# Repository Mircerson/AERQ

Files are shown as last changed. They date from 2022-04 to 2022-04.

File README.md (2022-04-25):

# AERQ - Indoor air quality monitor

## Introduction
This is the repository for AERQ, a USB-powered indoor air quality monitor using the
[here](/PCB/101-5/) Bosch BME688 sensor, running on mbed os.
It measures temperature, humidity, CO2 and IAQ using the BSEC 2.x library.
This data is then sent to The Things Network.
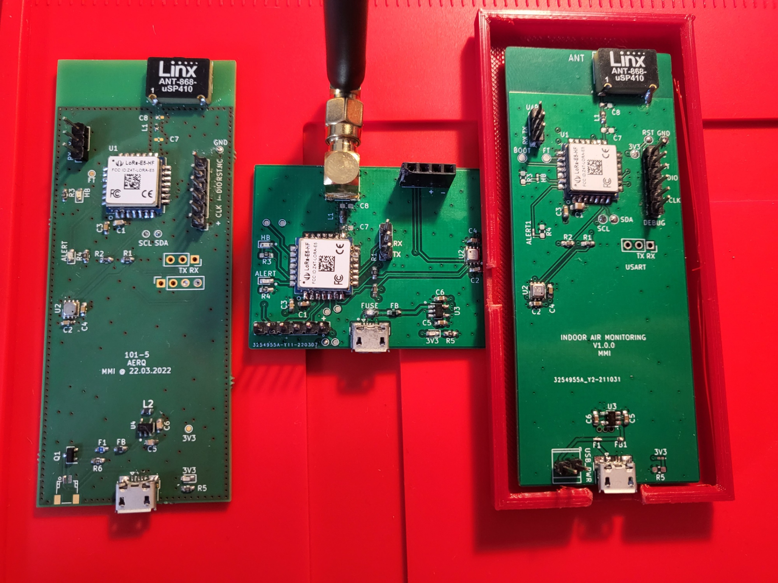
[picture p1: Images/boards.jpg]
Boards PCBs


## PCB
This project features a custom 4 layer board using the Seeed E5-LoRa and the Bosch BME688.
Two variants of the board, one with a chip antenna ( Linx USP-410 ) and one with a u.Fl connector.

Find more about the [STM32WL - Seeed E5-LoRa](https://www.seeedstudio.com/LoRa-E5-Wireless-Module-p-4745.html).

For the PCB with the integrated antenna, click here [here](/PCB/101-5/)

For the PCB with an external u.Fl connector, click [here](/PCB/101-3/)

## Code

The code runs on mbed os 6.15.1 with the latest LoRaWan stack.
Insert your TTN credentials in mbed_app.json before running the application.

This code features a custom target on mbed os which configures the RF switch properly and adds a few macros for the board.

See mbed_app.json and custom_targets.json for more details.

Thanks to [hallard](https://github.com/hallard/LoRa-E5-Breakout) for adding the support in the official mbed os custom target repository.

## Payload decoder for TTN
The payload should provide the following result:
TTN data TTN packet

```
function Decoder(bytes, port) {
  // Decode plain text; for testing only 
  //var statusFromDevice = String.fromCharCode.apply(null, bytes.slice(12,13))
  
  let StringOfBytes = String.fromCharCode.apply(null, bytes);
  
  var temperature;
  var humidity;
  var iaq;
  var iaqAccuracy;
  var CO2;
  
  const Array = StringOfBytes.split(" ");
  temperature = Array[0];
  humidity = Array[1];
  statusFromDevice = Array[2];
  iaq = Array[3];
  CO2 = Array[4];
  
  var statusToDisplay;
  
  if (statusFromDevice == "0"){
      statusToDisplay = "Device warming up";
  } else if(statusFromDevice == "1")
  {
      statusToDisplay = "Device is adjusting to the envinroment - calibrating";
  }else if(statusFromDevice == "2")
  {
      statusToDisplay = "Environment has changed - re-calibrating";
  }
  else if(statusFromDevice == "2")
  {
      statusToDisplay = "Environment has changed - re-calibrating";
  }
  else if(statusFromDevice == "3")
  {
      statusToDisplay = "Device is calibrated and running";
  }
  else if(statusFromDevice == "4")
  {
      statusToDisplay = "Error communicating with the IAQ sensor. Critical";
  }

  return {
      Humidity: humidity,
      //IAQAccuracy:String.fromCharCode.apply(null, bytes.slice(12,13)),
      IAQ:iaq,
      CO2:CO2,
      Temperature:temperature,
      Status:statusToDisplay
  };
}
```

## Android application

A simple KivyMD app was made for Android to receive packets:

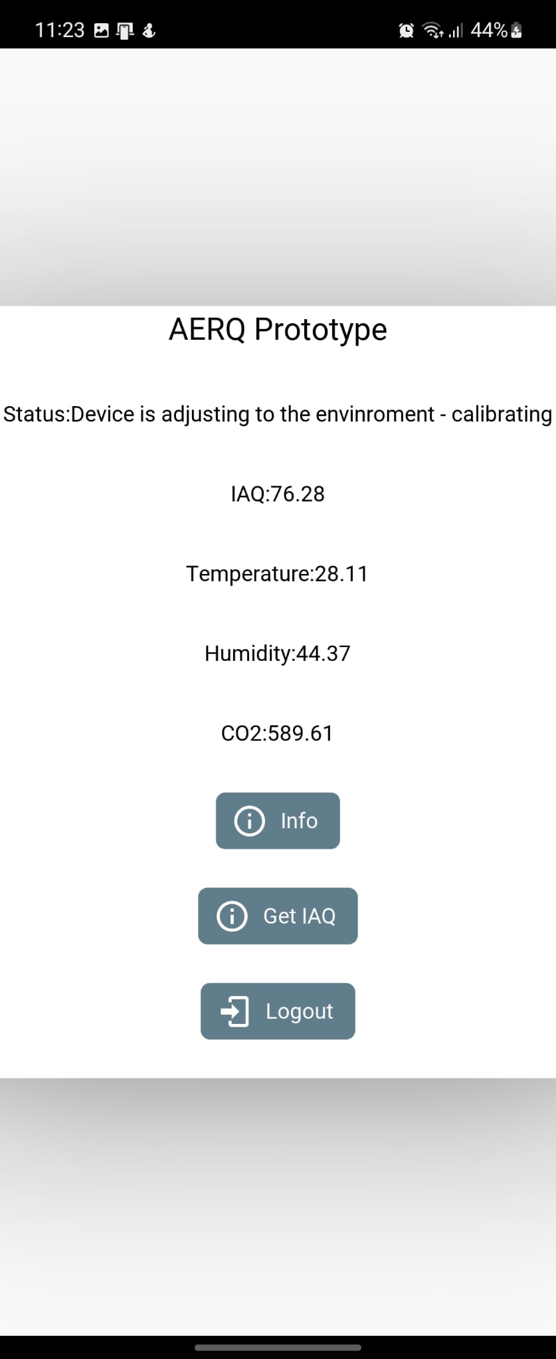
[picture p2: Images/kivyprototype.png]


## Azure IoT Central

Data can also be parsed through Azure IoT Hub to the Azure IoT Central

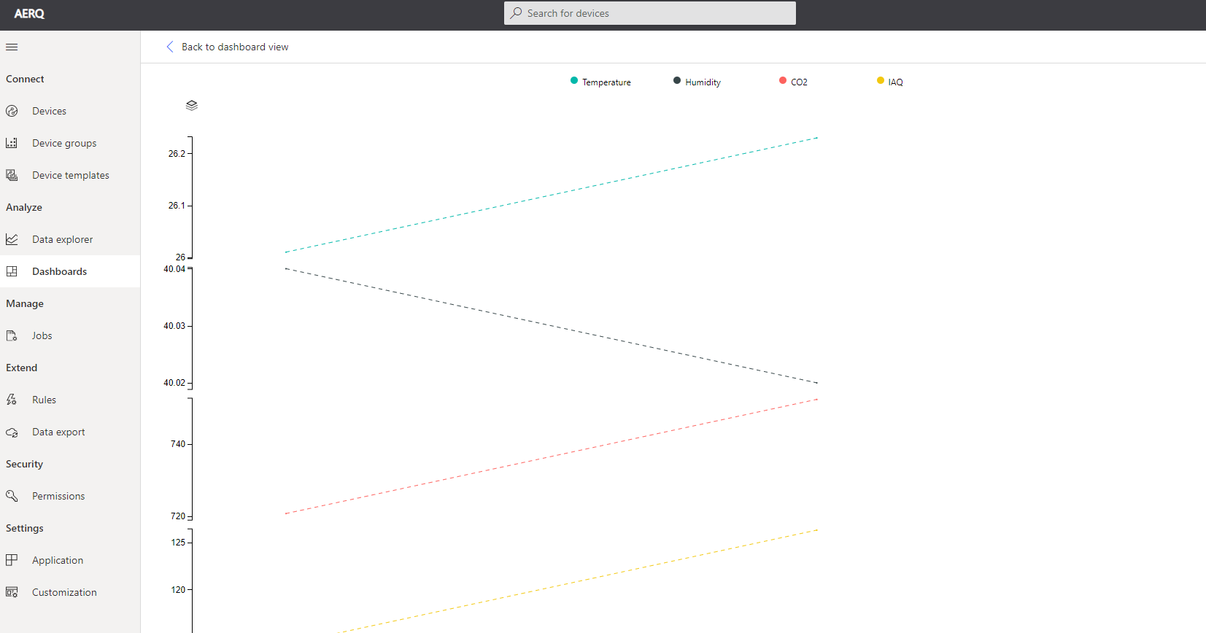
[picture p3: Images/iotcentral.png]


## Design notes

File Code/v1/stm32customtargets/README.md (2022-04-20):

# CUSTOM boards with STM32

Feel free to propose your custom boards support in mbed-os!

Table of Contents
=================

* [Usage](#usage)
* [GENERIC BOARDS](#generic-boards)
* [STM32F1](#stm32f1)
   * [BLUEPILL](#bluepill)
* [STM32F4](#stm32f4)
   * [CORE2](#core2)
* [STM32L0](#stm32l0)
   * [MURATA LPWAN Wireless Module](#murata-lpwan-wireless-module)
   * [MURATA Grasshopper](#murata-grasshopper)
   * [MURATA Gnat](#murata-gnat)
* [STM32L4](#stm32l4)
   * [STWIN SensorTile Wireless Industrial Node development kit](#stwin-sensortile-wireless-industrial-node-development-kit)
* [STM32WL](#stm32wl)
   * [Seeed Studio LoRa E5](#seeed-studio-lora-e5)
   * [Seeed Studio LoRa E5 Mini](#seeed-studio-lora-e5-mini)
   * [Seeed Studio LoRa E5 Dev Board](#seeed-studio-lora-e5-dev-board)
   * [Charles's LoRa-E5 breakout board](#charless-lora-e5-breakout-board)
   * [Charles's LoRa-E5 Tiny](#charless-lora-e5-tiny)
   * [RAK Wireless RAK3172](#rak-wireless-rak3172)
   * [Charles's RAK3172 breakout board](#charless-rak3172-breakout-board)
* [License](#license)
* [Contributions](#contributions)
   * [Automatic pull request checks](#automatic-pull-request-checks)
   * [Manual pull request checks](#manual-pull-request-checks)
   * [Automatic weekly non regression](#automatic-weekly-non-regression)

# Usage

In your application, clone this repo.

````
git clone https://github.com/ARMmbed/stm32customtargets.git
````

Copy custom_targets.json

````
cp stm32customtargets/custom_targets.json .
````

For some targets, you have to customize the configuration in your local mbed_app.json.

Details are explained for each target below, but you can also use the mbed_app_template.json file as example.

Then build your target with

- CLI1:
````
mbed compile -m XXX -t XXX
````

- CLI2:

Add in the application CMakeLists.txt:
````
add_subdirectory(stm32customtargets)
````
And build:
````
mbedtools compile -m XXX -t XXX
````

# GENERIC BOARDS

A "generic" board is a mbed-os "virtual" target with a pure STM32 MCU.

Goal is to make real custom boards creation very easy
as we ensure that build has alrady been tested.

Check the GENERIC_TARGET branch in this repo:

https://github.com/ARMmbed/stm32customtargets/tree/GENERIC_TARGET

# STM32F1

## BLUEPILL



MCU: STM32F103C8T6

TARGET: BLUEPILL_F103C8

source: https://os.mbed.com/users/hudakz/code/mbed-os-bluepill/

 (https://os.mbed.com/users/hudakz/code/STM32F103C8T6_Hello/)

# STM32F4

## CORE2 

MCU: STM32F407ZG

TARGET: CORE2

https://github.com/byq77/core2-mbed6-template



# STM32L0

## MURATA LPWAN Wireless Module

MCU: STM32L082CZ

TARGET: MTB_MURATA_ABZ

https://wireless.murata.com/type-abz-078.html

- LORA is not enabled by default. You need to update your local mbed_app.json file:

```json
{
    "target_overrides": {
        "MTB_MURATA_ABZ": {
            "target.components_add":             ["SX1276"],
            "sx1276-lora-driver.spi-mosi":       "LORA_SPI_MOSI",
            "sx1276-lora-driver.spi-miso":       "LORA_SPI_MISO",
            "sx1276-lora-driver.spi-sclk":       "LORA_SPI_SCLK",
            "sx1276-lora-driver.spi-cs":         "LORA_CS",
            "sx1276-lora-driver.reset":          "LORA_RESET",
            "sx1276-lora-driver.dio0":           "LORA_DIO0",
            "sx1276-lora-driver.dio1":           "LORA_DIO1",
            "sx1276-lora-driver.dio2":           "LORA_DIO2",
            "sx1276-lora-driver.dio3":           "LORA_DIO3",
            "sx1276-lora-driver.txctl":          "LORA_ANT_TX",
            "sx1276-lora-driver.rxctl":          "LORA_ANT_RX",
            "sx1276-lora-driver.pwr-amp-ctl":    "LORA_ANT_BOOST"
        }
    }
}
```

If you need to Low Power with VDD TXCO like [b-l072z-lrwan1](https://www.st.com/en/evaluation-tools/b-l072z-lrwan1.html), then you need JP9 positionned 1-2.
And reflect the pin used for that because it's defined to `NC` by default.

```json
{
    "target_overrides": {
        "MTB_MURATA_ABZ": {
            "sx1276-lora-driver.tcxo":           "PA_12"
        }
    }
}
```

## MURATA Grasshopper

MCU: STM32L082CZ



TARGET: GRASSHOPPER [TleraCorp](https://www.tindie.com/stores/tleracorp/)

- LORA is not enabled by default. You need to update your local mbed_app.json file:

```json
{
    "target_overrides": {
        "GRASSHOPPER": {
            "target.components_add":             ["SX1276"],
            "sx1276-lora-driver.spi-mosi":       "LORA_SPI_MOSI",
            "sx1276-lora-driver.spi-miso":       "LORA_SPI_MISO",
            "sx1276-lora-driver.spi-sclk":       "LORA_SPI_SCLK",
            "sx1276-lora-driver.spi-cs":         "LORA_CS",
            "sx1276-lora-driver.reset":          "LORA_RESET",
            "sx1276-lora-driver.dio0":           "LORA_DIO0",
            "sx1276-lora-driver.dio1":           "LORA_DIO1",
            "sx1276-lora-driver.dio2":           "LORA_DIO2",
            "sx1276-lora-driver.dio3":           "LORA_DIO3",
            "sx1276-lora-driver.txctl":          "LORA_ANT_TX",
            "sx1276-lora-driver.rxctl":          "LORA_ANT_RX",
            "sx1276-lora-driver.pwr-amp-ctl":    "LORA_ANT_BOOST",
            "sx1276-lora-driver.tcxo":           "LORA_VDD_TXCO"
        }
    }
}
```

## MURATA Gnat

MCU: STM32L082CZ



https://www.tindie.com/products/tleracorp/gnat-loragnss-asset-tracker/</img>

TARGET: GNAT [TleraCorp](https://www.tindie.com/products/tleracorp/gnat-loragnss-asset-tracker/)

- LORA is not enabled by default. You need to update your local mbed_app.json file:

```json
{
    "target_overrides": {
        "GNAT": {
            "target.components_add":             ["SX1276"],
            "sx1276-lora-driver.spi-mosi":       "LORA_SPI_MOSI",
            "sx1276-lora-driver.spi-miso":       "LORA_SPI_MISO",
            "sx1276-lora-driver.spi-sclk":       "LORA_SPI_SCLK",
            "sx1276-lora-driver.spi-cs":         "LORA_CS",
            "sx1276-lora-driver.reset":          "LORA_RESET",
            "sx1276-lora-driver.dio0":           "LORA_DIO0",
            "sx1276-lora-driver.dio1":           "LORA_DIO1",
            "sx1276-lora-driver.dio2":           "LORA_DIO2",
            "sx1276-lora-driver.dio3":           "LORA_DIO3",
            "sx1276-lora-driver.txctl":          "LORA_ANT_TX",
            "sx1276-lora-driver.rxctl":          "LORA_ANT_RX",
            "sx1276-lora-driver.pwr-amp-ctl":    "LORA_ANT_BOOST",
            "sx1276-lora-driver.tcxo":           "LORA_VDD_TXCO"
        }
    }
}
```

# STM32L4

## STWIN SensorTile Wireless Industrial Node development kit

MCU: STM32L4R9ZI



TARGET: STWIN

https://www.st.com/en/evaluation-tools/steval-stwinkt1.html

- BLE is enabled by default

# STM32WL

## Seeed Studio LoRa E5



MCU: STM32WLE5JC

TARGET: LORA_E5

https://www.seeedstudio.com/LoRa-E5-Wireless-Module-p-4745.html

LoRa-E5 use only RFO_HP for TX power, so for all boards using this module you need to add this to your `mbed_app.json` on section `target_overrides`

```json

   "LORA_E5": {
      "stm32wl-lora-driver.rf_switch_config": 2
   }
```

## Seeed Studio LoRa E5 Mini

TARGET: LORA_E5_MINI

Use LoRa E5 modulen basic board with USB/Serial and headers

https://www.seeedstudio.com/LoRa-E5-mini-STM32WLE5JC-p-4869.html

## Seeed Studio LoRa E5 Dev Board



TARGET: LORA_E5_DEV_BOARD

Use LoRa E5 module 

https://www.seeedstudio.com/LoRa-E5-Dev-Kit-p-4868.html

- RS485 Modbus
- all LoRa-E5 pins exposed
- temperature sensor
- buttons
- Led 
- GPIO to enable 3.3V and 5V for sensors
- some grove sonnectors (I2C, Serial, ..)
- Arduino form factor to plug shield

## Charles's LoRa-E5 breakout board

TARGET: LORA_E5_BREAKOUT



https://github.com/hallard/LoRa-E5-Breakout

Use LoRa E5 module and added

- FTDI 6 pins connector (:warning: **use 3.3V FTDI One, not 5V**)
- Exposed JTAG pins needed to flash module (PA13-SWDIO / PA14-SWCLK / RESET)
- Green Led on PB10 (LED1) reversed (1=OFF, 0=ON)
- Red Led on PB5 (LED2) reversed (1=OFF, 0=ON)

for debug LEDs of breakout so you need to add this to your `mbed_app.json` on section `target_overrides` and don't forget also the `rf_switch_config` seen above

```json
   "LORA_E5_BREAKOUT": {
      "stm32wl-lora-driver.rf_switch_config": 2,
      "stm32wl-lora-driver.debug_tx": "PB_5",
      "stm32wl-lora-driver.debug_rx": "PB_10",
      "stm32wl-lora-driver.debug_invert": 1
   }
```

## Charles's LoRa-E5 Tiny

TARGET: LORA_E5_TINY



https://github.com/hallard/LoRa-E5-Tiny

Use LoRa E5 module with CR2450 cell coin

- FTDI SMD 6 pads edge connector (:warning: **use 3.3V FTDI One, not 5V**)
- JTAG SMD 6 pads edge connector to flash module (PA13-SWDIO / PA14-SWCLK / PB3-SWO / RESET)
- Green Led on PB13
- Red Led on PA9
- 2 Tactile Switches (user PB4 and reset)
- Stemma QWIIC I2C connector
- PTH CR2450 battery holder

for debug LEDs of this board you need to add this to your `mbed_app.json` on section `target_overrides` and don't forget also the `rf_switch_config` seen above

```json
   "LORA_E5_TINY": {
      "stm32wl-lora-driver.rf_switch_config": 2,
      "stm32wl-lora-driver.debug_tx": "PB_13",
      "stm32wl-lora-driver.debug_rx": "PA_9"
   }
```

## RAK Wireless RAK3172



MCU: STM32WLE5CC

TARGET: RAK3172

RAK3172 use only RFO_HP for TX power and no TXCO so for all boards using this module you need to add this to your `mbed_app.json` on section `target_overrides`

```json

   "RAK3172": {
      "stm32wl-lora-driver.rf_switch_config": 2,
      "stm32wl-lora-driver.crystal_select" : 0
   }
```

## Charles's RAK3172 breakout board

TARGET: RAK3172_BREAKOUT



https://github.com/hallard/RAK3172-Breakout

Use RAK3172 and added

- FTDI 6 pins connector (:warning: **use 3.3V FTDI One, not 5V**)
- Exposed JTAG pins needed to flash module (PA13-SWDIO / PA14-SWCLK / RESET)
- Green Led on PA10 (LED1) reversed (1=OFF, 0=ON)
- Red Led on PA9 (LED2) reversed (1=OFF, 0=ON)
- SMD CR2450 battery holder

For debug LEDs of breakout so you need to add this to your `mbed_app.json` on section `target_overrides` and don't forget also the `rf_switch_config` and `crystal_select` seen above

```json
   "RAK3172_BREAKOUT": {
      "stm32wl-lora-driver.rf_switch_config": 2,
      "stm32wl-lora-driver.crystal_select" : 0,
      "stm32wl-lora-driver.debug_tx": "PA_10",
      "stm32wl-lora-driver.debug_rx": "PA_9",
      "stm32wl-lora-driver.debug_invert": 1
   }
```

# License

The software is provided under the [Apache-2.0 license](LICENSE-apache-2.0.txt).

# Contributions

Contributions to this project are accepted under the same license.

## Automatic pull request checks

- Build with CLI1 should be OK
```
python aci_build.py
```

- Build with CLI2 should be OK
```
python aci_build.py --cli2
```

Note that build is using the mbed_app_template.json file as configuration file.

- Standard Pin Names check should be OK

https://os.mbed.com/docs/mbed-os/latest/apis/standard-pin-names.html

```
python aci_build.py --pin
```

## Manual pull request checks

- Each target in custom_targets.json should be described in the README.md file

```
## <Full target name>

MCU: <STM32 MCU>

TARGET: <Target name for build>

<Link to a webpage describing this board>

<all other info is optional>

```

Note we limit image size to 200

- Keep Table of Contents up to date

## Automatic weekly non regression

A full non regression is executed each week-end

```
python aci_build.py --all
python aci_build.py --all --baremetal
python aci_build.py --all --cli2
python aci_build.py --all --cli2 --baremetal
python aci_build.py --all --pin
```

See in https://github.com/ARMmbed/stm32customtargets/actions

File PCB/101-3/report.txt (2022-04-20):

Info: Processing component "R2:/617AAB6E:Resistor_SMD:R_0603_1608Metric_Pad0.98x0.95mm_HandSolder".
Info: Processing component "GND1:/61981146:TestPoint:TestPoint_Pad_D1.5mm".
Info: Processing component "HB1:/61853D6C:LED_SMD:LED_0201_0603Metric_Pad0.64x0.40mm_HandSolder".
Info: Processing component "J1:/617BE23C:Connector_PinHeader_2.54mm:PinHeader_1x06_P2.54mm_Vertical".
Info: Processing component "J2:/61963625:TerminalBlock_TE-Connectivity:TerminalBlock_TE_282834-2_1x02_P2.54mm_Horizontal".
Info: Processing component "J3:/6180F261:Connector_USB:USB_Micro-B_Amphenol_10103594-0001LF_Horizontal".
Info: Processing component "3V3:/618832CE:LED_SMD:LED_0201_0603Metric_Pad0.64x0.40mm_HandSolder".
Info: Processing component "J5:/6195374E:Connector_PinSocket_2.54mm:PinSocket_1x03_P2.54mm_Vertical".
Info: Processing component "J6:/621E8932:Connector_PinHeader_2.54mm:PinHeader_1x01_P2.54mm_Vertical".
Info: Processing component "L1:/619CD27C:Capacitor_SMD:C_0603_1608Metric_Pad1.08x0.95mm_HandSolder".
Info: Processing component "R1:/617A9750:Resistor_SMD:R_0603_1608Metric_Pad0.98x0.95mm_HandSolder".
Info: Processing component "J4:/618D8888:Connector_PinSocket_2.54mm:PinSocket_1x03_P2.54mm_Vertical".
Info: Processing component "R3:/61856ED3:Resistor_SMD:R_0603_1608Metric_Pad0.98x0.95mm_HandSolder".
Info: Processing component "R4:/618772FD:Resistor_SMD:R_0603_1608Metric_Pad0.98x0.95mm_HandSolder".
Info: Processing component "R5:/618832D5:Resistor_SMD:R_0603_1608Metric_Pad0.98x0.95mm_HandSolder".
Info: Processing component "RST1:/6197BBD1:TestPoint:TestPoint_Pad_D1.5mm".
Info: Processing component "SCL1:/61906980:TestPoint:TestPoint_Pad_D1.5mm".
Info: Processing component "SDA1:/619098E4:TestPoint:TestPoint_Pad_D1.5mm".
Info: Processing component "U1:/6164AFD9:mmilibrary:LoRa-E5".
Info: Processing component "U2:/61802F1D:Package_LGA:Bosch_LGA-8_3x3mm_P0.8mm_ClockwisePinNumbering".
Info: Processing component "U3:/61787A56:Package_TO_SOT_SMD:SOT-23-5_HandSoldering".
Info: Processing component "C3:/61781AAA:Capacitor_SMD:C_0603_1608Metric_Pad1.08x0.95mm_HandSolder".
Info: Processing component "3V3_OUT1:/618F8508:TestPoint:TestPoint_Pad_D1.5mm".
Info: Processing component "ALERT1:/618772F6:LED_SMD:LED_0201_0603Metric_Pad0.64x0.40mm_HandSolder".
Info: Processing component "BOOT_TP1:/6197CBDD:TestPoint:TestPoint_Pad_D1.5mm".
Info: Processing component "C1:/61772FC0:Capacitor_SMD:C_0603_1608Metric_Pad1.08x0.95mm_HandSolder".
Info: Processing component "C2:/6179A095:Capacitor_SMD:C_0603_1608Metric_Pad1.08x0.95mm_HandSolder".
Info: Processing component "C4:/6179A0A9:Capacitor_SMD:C_0603_1608Metric_Pad1.08x0.95mm_HandSolder".
Info: Processing component "C5:/618C5A71:Capacitor_SMD:C_0603_1608Metric_Pad1.08x0.95mm_HandSolder".
Info: Processing component "C6:/618C69FF:Capacitor_SMD:C_0603_1608Metric_Pad1.08x0.95mm_HandSolder".
Info: Processing component "C7:/619CC8DD:Capacitor_SMD:C_0603_1608Metric_Pad1.08x0.95mm_HandSolder".
Info: Processing component "C8:/619CDAB6:Capacitor_SMD:C_0603_1608Metric_Pad1.08x0.95mm_HandSolder".
Info: Processing component "E1:/619C1B4A:mmilibrary:XDCR_ANT-868-USP410".
Info: Processing component "FB1:/618FFA2B:Capacitor_SMD:C_0201_0603Metric_Pad0.64x0.40mm_HandSolder".
Info: Processing component "FT1:/619C09A1:TestPoint:TestPoint_Pad_D1.5mm".
Info: Processing component "F1:/61906770:Capacitor_SMD:C_0201_0603Metric_Pad0.64x0.40mm_HandSolder".
Add net Net-(U1-Pad20).
Add net ADC_IN3.
Connect U1 pin 7 to ADC_IN3.
Add net Net-(U1-Pad11).
Connect U1 pin 11 to Net-(U1-Pad11).
Add net Net-(U1-Pad8).
Connect U1 pin 8 to Net-(U1-Pad8).
Add net Net-(U1-Pad12).
Connect U1 pin 12 to Net-(U1-Pad12).
Add net Net-(U1-Pad13).
Connect U1 pin 13 to Net-(U1-Pad13).
Change GND reference to GND1.
Connect U1 pin 20 to Net-(U1-Pad20).
Add net Net-(U1-Pad21).
Connect U1 pin 21 to Net-(U1-Pad21).
Add net Net-(U1-Pad25).
Connect U1 pin 25 to Net-(U1-Pad25).
Add net Net-(U1-Pad26).
Connect U1 pin 26 to Net-(U1-Pad26).
Change 3V3 reference to 3V3_OUT1.
Connect USB_PWR pin 4 to Net-(J3-Pad4).
Add net Net-(J1-Pad6).
Add net Net-(J3-Pad2).
Connect USB_PWR pin 2 to Net-(J3-Pad2).
Change ANT reference to E1.
Change UART reference to J4.
Change USB_PWR reference to J3.
Change USART reference to J5.
Add net Net-(E1-Pad2).
Add J6 (footprint "Connector_PinHeader_2.54mm:PinHeader_1x01_P2.54mm_Vertical").
Connect ANT pin 2 to Net-(E1-Pad2).
Connect DEBUG pin 6 to Net-(J1-Pad6).
Connect USB_PWR pin 3 to Net-(J3-Pad3).
Change DEBUG reference to J1.
Change FT reference to FT1.
Add net Net-(J3-Pad3).
Change HB reference to HB1.
Change RST reference to RST1.
Change BOOT reference to BOOT_TP1.
Change SCL reference to SCL1.
Add net Net-(J3-Pad4).
Change SDA reference to SDA1.

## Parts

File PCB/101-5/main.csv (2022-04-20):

Source: | C:\Github\Indoor-Air-Quality-BME688-STM32WLE5JC\KiCad\Indoor Air Monitor\101-4\main.sch
Date: | 13/03/2022 15:14
Tool: | Eeschema (5.1.10)-1
Generator: | C:\Program Files\KiCad\bin\scripting\plugins/bom_csv_grouped_by_value.py
Component Count: | 35
Individual Components:
Item | Qty | Reference(s) | Value | LibPart | Footprint | Datasheet | MANUFACTURER | MAXIMUM_PACKAGE_HEIGHT | PARTREV | STANDARD
 |  | 3V1 | PWR | Device:LED_Small | LED_SMD:LED_0603_1608Metric_Pad1.05x0.95mm_HandSolder | ~
 |  | 3V3_OUT1 | 3V3_TP | Connector:TestPoint_Small | TestPoint:TestPoint_Pad_D1.0mm | ~
 |  | ALERT1 | ALERT | Device:LED_Small | LED_SMD:LED_0603_1608Metric_Pad1.05x0.95mm_HandSolder | ~
 |  | C1 | 100nF | Device:C_Small | Capacitor_SMD:C_0603_1608Metric_Pad1.08x0.95mm_HandSolder | ~
 |  | C2 | 100nF | Device:C_Small | Capacitor_SMD:C_0603_1608Metric_Pad1.08x0.95mm_HandSolder | ~
 |  | C3 | 4.7uF | Device:C_Small | Capacitor_SMD:C_0603_1608Metric_Pad1.08x0.95mm_HandSolder | ~
 |  | C4 | 100nF | Device:C_Small | Capacitor_SMD:C_0603_1608Metric_Pad1.08x0.95mm_HandSolder | ~
 |  | C5 | 1uF | Device:C_Small | Capacitor_SMD:C_0603_1608Metric_Pad1.08x0.95mm_HandSolder | ~
 |  | C6 | 1uF | Device:C_Small | Capacitor_SMD:C_0603_1608Metric_Pad1.08x0.95mm_HandSolder | ~
 |  | C7 | DNP | Device:C_Small | Capacitor_SMD:C_0603_1608Metric_Pad1.08x0.95mm_HandSolder | ~
 |  | C8 | DNP | Device:C_Small | Capacitor_SMD:C_0603_1608Metric_Pad1.08x0.95mm_HandSolder | ~
 |  | CON_DEBUG1 | Conn_01x02_Male | Connector:Conn_01x02_Male | Connector_PinHeader_2.54mm:PinHeader_1x02_P2.54mm_Vertical | ~
 |  | E1 | ANT-868-USP410 | main-rescue:ANT-868-USP410-Antenna | mmilibrary:XDCR_ANT-868-USP410 |  | Linx | 2.9 mm | DS20241-03ANT | Manufacturer Recommendations
 |  | F1 | 300mA Fuse | Device:Polyfuse_Small | Resistor_SMD:R_0603_1608Metric_Pad0.98x0.95mm_HandSolder | ~
 |  | FB1 | FB | Device:Ferrite_Bead_Small | Resistor_SMD:R_0603_1608Metric_Pad0.98x0.95mm_HandSolder | ~
 |  | FT1 | FT_TP | Connector:TestPoint_Small | TestPoint:TestPoint_Pad_D1.0mm | ~
 |  | GND1 | GND | Connector:TestPoint_Small | TestPoint:TestPoint_Pad_D1.0mm | ~
 |  | HB1 | HEARTBEAT | Device:LED_Small | LED_SMD:LED_0603_1608Metric_Pad1.05x0.95mm_HandSolder | ~
 |  | J1 | 1x6 header | Connector:Conn_01x06_Male | Connector_PinHeader_2.54mm:PinHeader_1x06_P2.54mm_Vertical | ~
 |  | J2 | Screw_Terminal_01x02 | Connector:Screw_Terminal_01x02 | TerminalBlock_TE-Connectivity:TerminalBlock_TE_282834-2_1x02_P2.54mm_Horizontal | ~
 |  | J4 | Conn_01x03 | Connector_Generic:Conn_01x03 | Connector_PinSocket_2.54mm:PinSocket_1x03_P2.54mm_Vertical | ~
 |  | J5 | Conn_01x03 | Connector_Generic:Conn_01x03 | Connector_PinSocket_2.54mm:PinSocket_1x03_P2.54mm_Vertical | ~
 |  | J6 | Conn_01x04_Female | Connector:Conn_01x04_Female | Connector_PinSocket_2.54mm:PinSocket_1x04_P2.54mm_Vertical | ~
 |  | L1 | DNP | Device:L_Small | Capacitor_SMD:C_0603_1608Metric_Pad1.08x0.95mm_HandSolder | ~
 |  | R1 | 4.7k | Device:R_Small | Resistor_SMD:R_0603_1608Metric_Pad0.98x0.95mm_HandSolder | ~
 |  | R2 | 4.7k | Device:R_Small | Resistor_SMD:R_0603_1608Metric_Pad0.98x0.95mm_HandSolder | ~
 |  | R3 | 1.8k | Device:R_Small | Resistor_SMD:R_0603_1608Metric_Pad0.98x0.95mm_HandSolder | ~
 |  | R4 | 1.8k | Device:R_Small | Resistor_SMD:R_0603_1608Metric_Pad0.98x0.95mm_HandSolder | ~
 |  | R5 | 1.8k | Device:R_Small | Resistor_SMD:R_0603_1608Metric_Pad0.98x0.95mm_HandSolder | ~
 |  | SCL1 | SCL_TP | Connector:TestPoint_Small | TestPoint:TestPoint_Pad_D1.0mm | ~
 |  | SDA1 | SDA_TP | Connector:TestPoint_Small | TestPoint:TestPoint_Pad_D1.0mm | ~
 |  | U1 | LoRa-E5 | LoRa-E5:LoRa-E5 | mmilibrary:LoRa-E5
 |  | U2 | BME688 | main-rescue:BME688-BME688 | Package_LGA:Bosch_LGA-8_3x3mm_P0.8mm_ClockwisePinNumbering
 |  | U3 | TLV70333DBVR | mmiSymbol:TLV70333DBVR | Package_TO_SOT_SMD:SOT-23-5_HandSoldering | https://www.ti.com/lit/ds/symlink/tlv703.pdf?ts=1635229150191
 |  | USB_PWR1 | USB_B_Micro | Connector:USB_B_Micro | Connector_USB:USB_Micro-B_Amphenol_10103594-0001LF_Horizontal | ~
Collated Components:
Item | Qty | Reference(s) | Value | LibPart | Footprint | Datasheet | MANUFACTURER | MAXIMUM_PACKAGE_HEIGHT | PARTREV | STANDARD
1 | 1 | 3V1 | PWR | Device:LED_Small | LED_SMD:LED_0603_1608Metric_Pad1.05x0.95mm_HandSolder | ~
2 | 1 | 3V3_OUT1 | 3V3_TP | Connector:TestPoint_Small | TestPoint:TestPoint_Pad_D1.0mm | ~
3 | 1 | ALERT1 | ALERT | Device:LED_Small | LED_SMD:LED_0603_1608Metric_Pad1.05x0.95mm_HandSolder | ~
4 | 3 | C1, C2, C4 | 100nF | Device:C_Small | Capacitor_SMD:C_0603_1608Metric_Pad1.08x0.95mm_HandSolder | ~
5 | 1 | C3 | 4.7uF | Device:C_Small | Capacitor_SMD:C_0603_1608Metric_Pad1.08x0.95mm_HandSolder | ~
6 | 2 | C5, C6 | 1uF | Device:C_Small | Capacitor_SMD:C_0603_1608Metric_Pad1.08x0.95mm_HandSolder | ~
7 | 2 | C7, C8 | DNP | Device:C_Small | Capacitor_SMD:C_0603_1608Metric_Pad1.08x0.95mm_HandSolder | ~
8 | 1 | CON_DEBUG1 | Conn_01x02_Male | Connector:Conn_01x02_Male | Connector_PinHeader_2.54mm:PinHeader_1x02_P2.54mm_Vertical | ~
9 | 1 | E1 | ANT-868-USP410 | main-rescue:ANT-868-USP410-Antenna | mmilibrary:XDCR_ANT-868-USP410 |  | Linx | 2.9 mm | DS20241-03ANT | Manufacturer Recommendations
10 | 1 | F1 | 300mA Fuse | Device:Polyfuse_Small | Resistor_SMD:R_0603_1608Metric_Pad0.98x0.95mm_HandSolder | ~
11 | 1 | FB1 | FB | Device:Ferrite_Bead_Small | Resistor_SMD:R_0603_1608Metric_Pad0.98x0.95mm_HandSolder | ~
12 | 1 | FT1 | FT_TP | Connector:TestPoint_Small | TestPoint:TestPoint_Pad_D1.0mm | ~
13 | 1 | GND1 | GND | Connector:TestPoint_Small | TestPoint:TestPoint_Pad_D1.0mm | ~
14 | 1 | HB1 | HEARTBEAT | Device:LED_Small | LED_SMD:LED_0603_1608Metric_Pad1.05x0.95mm_HandSolder | ~
15 | 1 | J1 | 1x6 header | Connector:Conn_01x06_Male | Connector_PinHeader_2.54mm:PinHeader_1x06_P2.54mm_Vertical | ~
16 | 1 | J2 | Screw_Terminal_01x02 | Connector:Screw_Terminal_01x02 | TerminalBlock_TE-Connectivity:TerminalBlock_TE_282834-2_1x02_P2.54mm_Horizontal | ~
17 | 2 | J4, J5 | Conn_01x03 | Connector_Generic:Conn_01x03 | Connector_PinSocket_2.54mm:PinSocket_1x03_P2.54mm_Vertical | ~
18 | 1 | J6 | Conn_01x04_Female | Connector:Conn_01x04_Female | Connector_PinSocket_2.54mm:PinSocket_1x04_P2.54mm_Vertical | ~
19 | 1 | L1 | DNP | Device:L_Small | Capacitor_SMD:C_0603_1608Metric_Pad1.08x0.95mm_HandSolder | ~
20 | 2 | R1, R2 | 4.7k | Device:R_Small | Resistor_SMD:R_0603_1608Metric_Pad0.98x0.95mm_HandSolder | ~
21 | 3 | R3, R4, R5 | 1.8k | Device:R_Small | Resistor_SMD:R_0603_1608Metric_Pad0.98x0.95mm_HandSolder | ~
22 | 1 | SCL1 | SCL_TP | Connector:TestPoint_Small | TestPoint:TestPoint_Pad_D1.0mm | ~
23 | 1 | SDA1 | SDA_TP | Connector:TestPoint_Small | TestPoint:TestPoint_Pad_D1.0mm | ~
24 | 1 | U1 | LoRa-E5 | LoRa-E5:LoRa-E5 | mmilibrary:LoRa-E5
25 | 1 | U2 | BME688 | main-rescue:BME688-BME688 | Package_LGA:Bosch_LGA-8_3x3mm_P0.8mm_ClockwisePinNumbering
26 | 1 | U3 | TLV70333DBVR | mmiSymbol:TLV70333DBVR | Package_TO_SOT_SMD:SOT-23-5_HandSoldering | https://www.ti.com/lit/ds/symlink/tlv703.pdf?ts=1635229150191
27 | 1 | USB_PWR1 | USB_B_Micro | Connector:USB_B_Micro | Connector_USB:USB_Micro-B_Amphenol_10103594-0001LF_Horizontal | ~

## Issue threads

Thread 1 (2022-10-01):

Antenna performance?

marcpiulachs, 2022-10-01:
Hi, I'm looking to build a similar device with a Lora E5 with sensor and since I'm not an expert on the RF field and looking for similar designs to learn from I came across your AERQ project, I would prefer to use a built in antena on the pcb rather than an external one but I'm a little worried about the performance, have you tested the range with your device?

Mircerson, 2022-10-02:
Range is pretty good. Maximum I got was around 1 km with the Linx antenna( with LoS but in an urban environment ). Expect to get a whole building covered.

Keep in mind if you end up doing a low-power design that the E5-LoRa is hard wired to use the High TX power path, so it does use quite a bit of power to do the transmission.

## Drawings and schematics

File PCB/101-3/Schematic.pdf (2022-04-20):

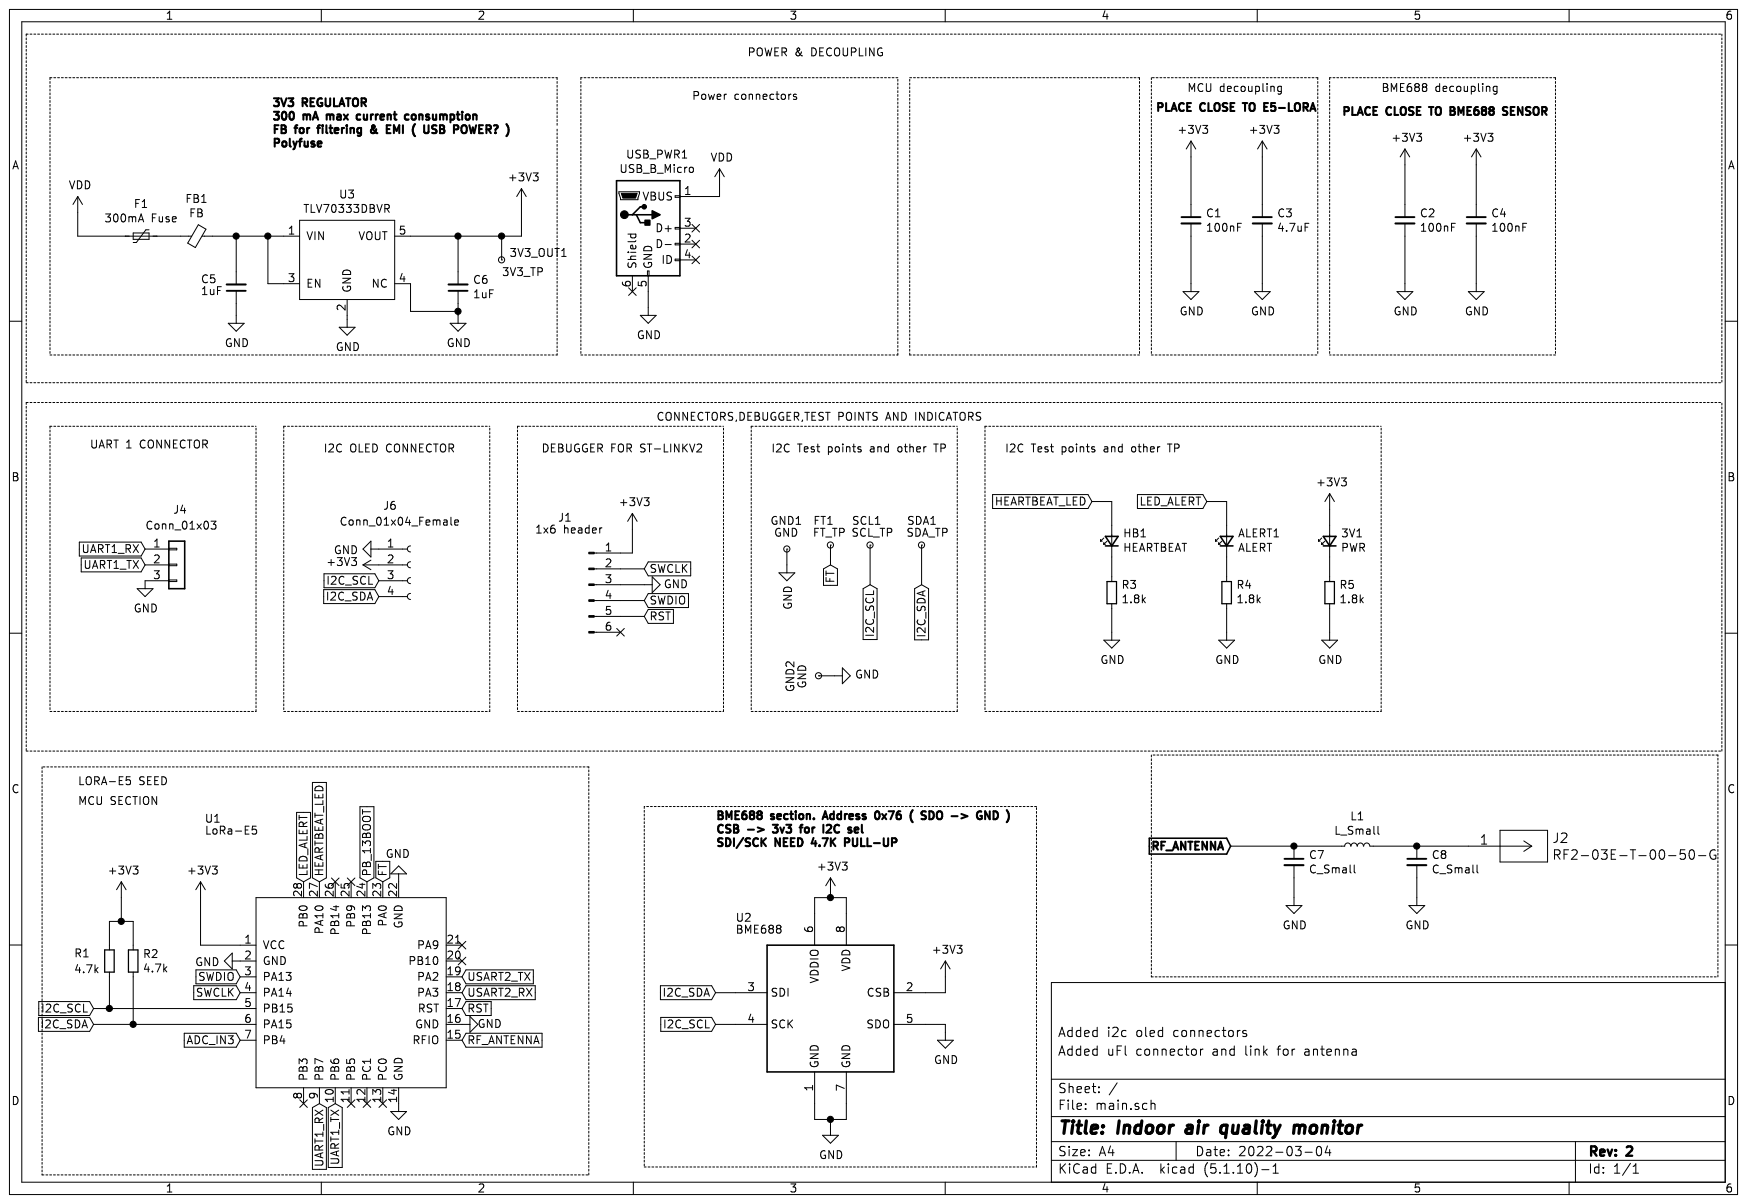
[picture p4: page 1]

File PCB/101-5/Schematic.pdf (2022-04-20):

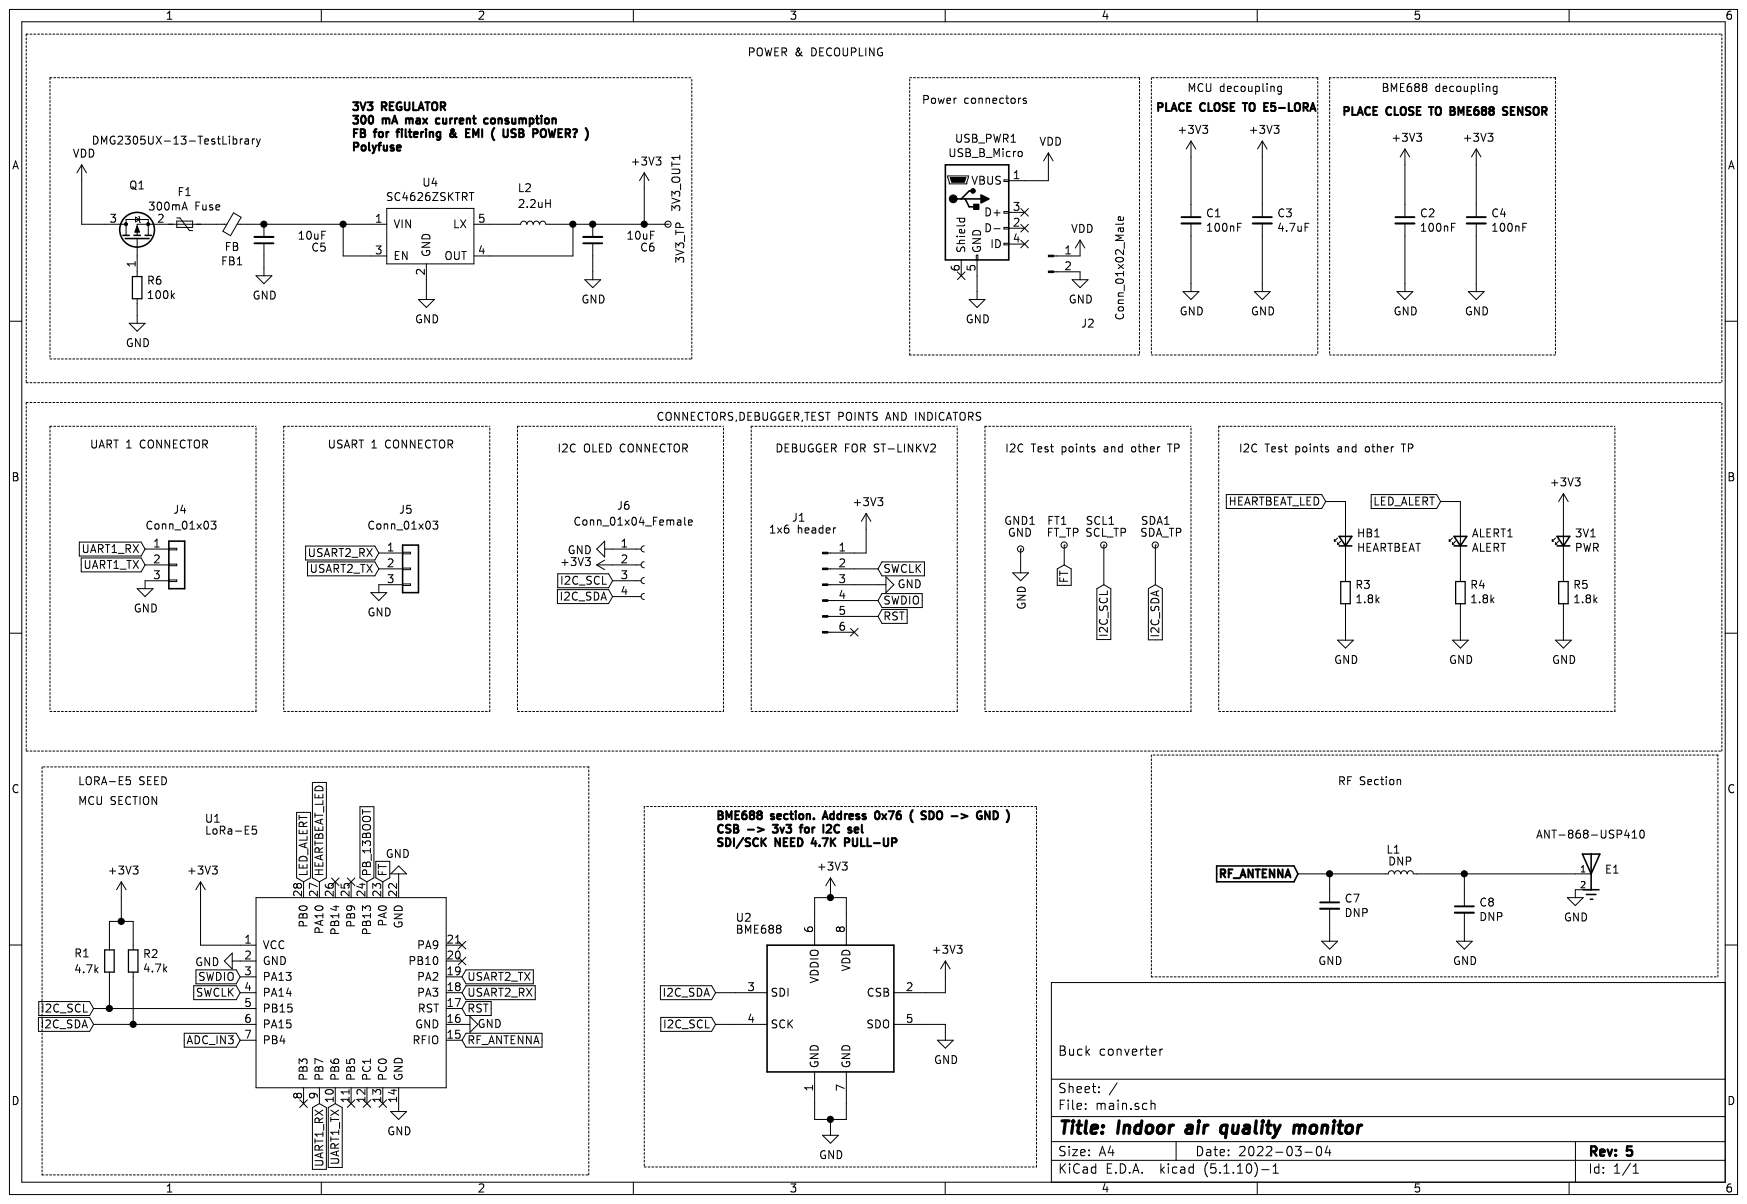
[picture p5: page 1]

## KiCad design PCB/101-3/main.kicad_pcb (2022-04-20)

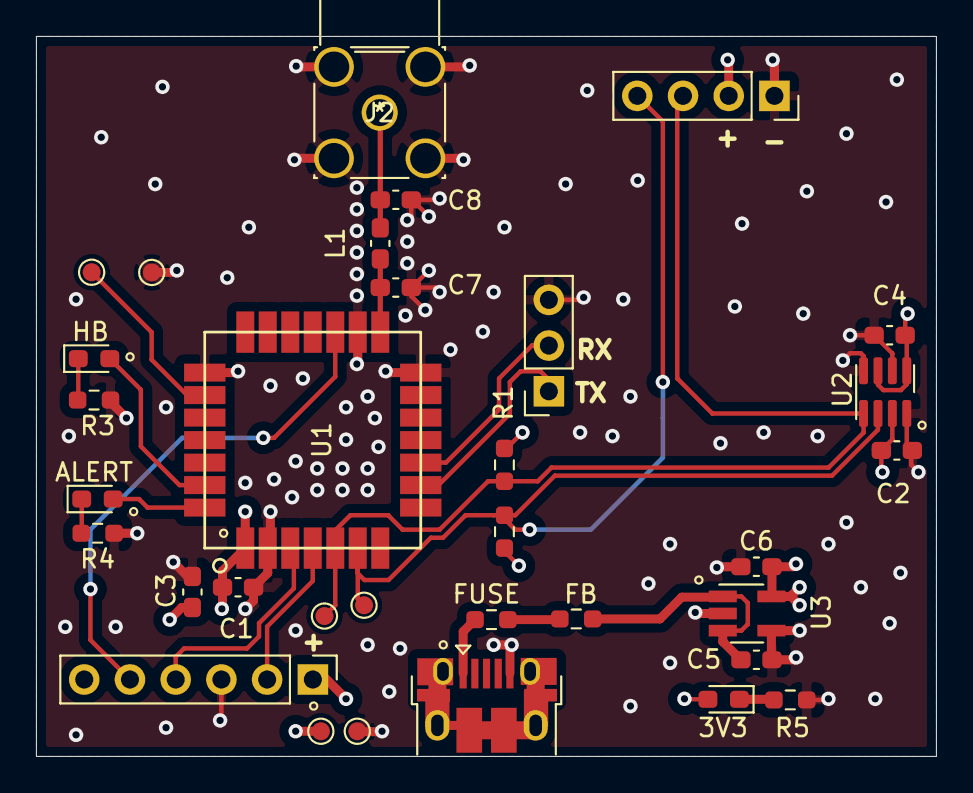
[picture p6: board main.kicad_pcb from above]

Board: 4 copper layers, 50.0 x 40.0 mm, 33 parts (0 on the bottom side), 20 nets.

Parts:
3V1: PWR; LED_0603_1608Metric_Pad1.05x0.95mm_HandSolder
3V3_OUT1: 3V3_TP; TestPoint_Pad_D1.0mm
ALERT1: ALERT; LED_0603_1608Metric_Pad1.05x0.95mm_HandSolder
C1, C2, C4: 100nF; C_0603_1608Metric_Pad1.08x0.95mm_HandSolder
C3: 4.7uF; C_0603_1608Metric_Pad1.08x0.95mm_HandSolder
C5, C6: 1uF; C_0603_1608Metric_Pad1.08x0.95mm_HandSolder
C7, C8: C_Small; C_0603_1608Metric_Pad1.08x0.95mm_HandSolder
F1: 300mA Fuse; R_0603_1608Metric_Pad0.98x0.95mm_HandSolder
FB1: FB; R_0603_1608Metric_Pad0.98x0.95mm_HandSolder
FT1: FT_TP; TestPoint_Pad_D1.0mm
GND1, GND2: GND; TestPoint_Pad_D1.0mm
HB1: HEARTBEAT; LED_0603_1608Metric_Pad1.05x0.95mm_HandSolder
J1: 1x6 header; PinHeader_1x06_P2.54mm_Vertical
J2: RF2-03E-T-00-50-G
J4: Conn_01x03; PinSocket_1x03_P2.54mm_Vertical
J6: Conn_01x04_Female; PinSocket_1x04_P2.54mm_Vertical
L1: L_Small; C_0603_1608Metric_Pad1.08x0.95mm_HandSolder
R1, R2: 4.7k; R_0603_1608Metric_Pad0.98x0.95mm_HandSolder
R3, R4, R5: 1.8k; R_0603_1608Metric_Pad0.98x0.95mm_HandSolder
SCL1: SCL_TP; TestPoint_Pad_D1.0mm
SDA1: SDA_TP; TestPoint_Pad_D1.0mm
U1: LoRa-E5
U2: BME688; Bosch_LGA-8_3x3mm_P0.8mm_ClockwisePinNumbering
U3: TLV70333DBVR; SOT-23-5_HandSoldering
USB_PWR1: USB_B_Micro; USB_Micro-B_Amphenol_10103594-0001LF_Horizontal

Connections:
+3V3: 3V1.2, 3V3_OUT1.1, C1.1, C2.1, C3.1, C4.1, C6.2, J1.1, J6.2, R1.1, R2.1, U1.1, U2.2, U2.6, U2.8, U3.5
FT: FT1.1, U1.23
GND: C1.2, C2.2, C3.2, C4.2, C5.1, C6.1, C7.2, C8.2, GND1.1, GND2.1, J1.3, J2.2, J2.3, J2.4, J2.5, J4.3, J6.1, R3.1, R4.1, R5.1, U1.2, U1.14, U1.16, U1.22, U2.1, U2.5, U2.7, U3.2, U3.4, USB_PWR1.5
HEARTBEAT_LED: HB1.2, U1.27
I2C_SCL: J6.3, R1.2, SCL1.1, U1.5, U2.4
I2C_SDA: J6.4, R2.2, SDA1.1, U1.6, U2.3
LED_ALERT: ALERT1.2, U1.28
unnamed: 3V1.1, R5.2
unnamed: ALERT1.1, R4.2
unnamed: C5.2, FB1.1, U3.1, U3.3
unnamed: C8.1, J2.1, L1.2
unnamed: F1.1, FB1.2
unnamed: HB1.1, R3.2
RF_ANTENNA: C7.1, L1.1, U1.15
RST: J1.5, U1.17
SWCLK: J1.2, U1.4
SWDIO: J1.4, U1.3
UART1_RX: J4.1, U1.9
UART1_TX: J4.2, U1.10
VDD: F1.2, USB_PWR1.1

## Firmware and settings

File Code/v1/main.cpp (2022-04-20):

#include "mbed.h"
#include "SensorFusion.hpp"
#include <stdio.h>




static EventQueue mainThread(5 *EVENTS_EVENT_SIZE);


DigitalOut hb(HEARTBEAT_LED);
SensorFusion sensorManagement;


void doHb();



int main()
{
    sensorManagement.start();
    mainThread.dispatch_forever();
}
 
void doHb()
{
    hb = !hb;
}

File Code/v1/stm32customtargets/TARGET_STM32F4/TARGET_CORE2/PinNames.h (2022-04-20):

/* mbed Microcontroller Library
 *******************************************************************************
 * Copyright (c) 2018, STMicroelectronics
 * All rights reserved.
 *
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
 * THIS SOFTWARE IS PROVIDED BY THE COPYRIGHT HOLDERS AND CONTRIBUTORS "AS IS"
 * AND ANY EXPRESS OR IMPLIED WARRANTIES, INCLUDING, BUT NOT LIMITED TO, THE
 * IMPLIED WARRANTIES OF MERCHANTABILITY AND FITNESS FOR A PARTICULAR PURPOSE ARE
 * DISCLAIMED. IN NO EVENT SHALL THE COPYRIGHT HOLDER OR CONTRIBUTORS BE LIABLE
 * FOR ANY DIRECT, INDIRECT, INCIDENTAL, SPECIAL, EXEMPLARY, OR CONSEQUENTIAL
 * DAMAGES (INCLUDING, BUT NOT LIMITED TO, PROCUREMENT OF SUBSTITUTE GOODS OR
 * SERVICES; LOSS OF USE, DATA, OR PROFITS; OR BUSINESS INTERRUPTION) HOWEVER
 * CAUSED AND ON ANY THEORY OF LIABILITY, WHETHER IN CONTRACT, STRICT LIABILITY,
 * OR TORT (INCLUDING NEGLIGENCE OR OTHERWISE) ARISING IN ANY WAY OUT OF THE USE
 * OF THIS SOFTWARE, EVEN IF ADVISED OF THE POSSIBILITY OF SUCH DAMAGE.
 *******************************************************************************
 */

#ifndef MBED_PINNAMES_H
#define MBED_PINNAMES_H

#include "cmsis.h"
#include "PinNamesTypes.h"

#ifdef __cplusplus
extern "C" {
#endif

typedef enum {
    ALT0  = 0x100,
    ALT1  = 0x200,
    ALT2  = 0x300,
    ALT3  = 0x400
} ALTx;

typedef enum {
    PA_0  = 0x00,
    PA_0_ALT0 = PA_0 | ALT0,
    PA_0_ALT1 = PA_0 | ALT1,
    PA_1  = 0x01,
    PA_1_ALT0 = PA_1 | ALT0,
    PA_1_ALT1 = PA_1 | ALT1,
    PA_2  = 0x02,
    PA_2_ALT0 = PA_2 | ALT0,
    PA_2_ALT1 = PA_2 | ALT1,
    PA_3  = 0x03,
    PA_3_ALT0 = PA_3 | ALT0,
    PA_3_ALT1 = PA_3 | ALT1,
    PA_4  = 0x04,
    PA_4_ALT0 = PA_4 | ALT0,
    PA_5  = 0x05,
    PA_5_ALT0 = PA_5 | ALT0,
    PA_6  = 0x06,
    PA_6_ALT0 = PA_6 | ALT0,
    PA_7  = 0x07,
    PA_7_ALT0 = PA_7 | ALT0,
    PA_7_ALT1 = PA_7 | ALT1,
    PA_7_ALT2 = PA_7 | ALT2,
    PA_8  = 0x08,
    PA_9  = 0x09,
    PA_10 = 0x0A,
    PA_11 = 0x0B,
    PA_12 = 0x0C,
    PA_13 = 0x0D,
    PA_14 = 0x0E,
    PA_15 = 0x0F,
    PA_15_ALT0 = PA_15 | ALT0,

    PB_0  = 0x10,
    PB_0_ALT0 = PB_0 | ALT0,
    PB_0_ALT1 = PB_0 | ALT1,
    PB_1  = 0x11,
    PB_1_ALT0 = PB_1 | ALT0,
    PB_1_ALT1 = PB_1 | ALT1,
    PB_2  = 0x12,
    PB_3  = 0x13,
    PB_3_ALT0 = PB_3 | ALT0,
    PB_4  = 0x14,
    PB_4_ALT0 = PB_4 | ALT0,
    PB_4_ALT1 = PB_4 | ALT1,
    PB_5  = 0x15,
    PB_5_ALT0 = PB_5 | ALT0,
    PB_5_ALT1 = PB_5 | ALT1,
    PB_6  = 0x16,
    PB_7  = 0x17,
    PB_8  = 0x18,
    PB_8_ALT0 = PB_8 | ALT0,
    PB_8_ALT1 = PB_8 | ALT1,
    PB_9  = 0x19,
    PB_9_ALT0 = PB_9 | ALT0,
    PB_9_ALT1 = PB_9 | ALT1,
    PB_10 = 0x1A,
    PB_11 = 0x1B,
    PB_12 = 0x1C,
    PB_13 = 0x1D,
    PB_14 = 0x1E,
    PB_14_ALT0 = PB_14 | ALT0,
    PB_14_ALT1 = PB_14 | ALT1,
    PB_15 = 0x1F,
    PB_15_ALT0 = PB_15 | ALT0,
    PB_15_ALT1 = PB_15 | ALT1,

    PC_0  = 0x20,
    PC_0_ALT0 = PC_0 | ALT0,
    PC_0_ALT1 = PC_0 | ALT1,
    PC_1  = 0x21,
    PC_1_ALT0 = PC_1 | ALT0,
    PC_1_ALT1 = PC_1 | ALT1,
    PC_2  = 0x22,
    PC_2_ALT0 = PC_2 | ALT0,
    PC_2_ALT1 = PC_2 | ALT1,
    PC_3  = 0x23,
    PC_3_ALT0 = PC_3 | ALT0,
    PC_3_ALT1 = PC_3 | ALT1,
    PC_4  = 0x24,
    PC_4_ALT0 = PC_4 | ALT0,
    PC_5  = 0x25,
    PC_5_ALT0 = PC_5 | ALT0,
    PC_6  = 0x26,
    PC_6_ALT0 = PC_6 | ALT0,
    PC_7  = 0x27,
    PC_7_ALT0 = PC_7 | ALT0,
    PC_8  = 0x28,
    PC_8_ALT0 = PC_8 | ALT0,
    PC_9  = 0x29,
    PC_9_ALT0 = PC_9 | ALT0,
    PC_10 = 0x2A,
    PC_10_ALT0 = PC_10 | ALT0,
    PC_11 = 0x2B,
    PC_11_ALT0 = PC_11 | ALT0,
    PC_12 = 0x2C,
    PC_13 = 0x2D,
    PC_14 = 0x2E,
    PC_15 = 0x2F,

    PD_0  = 0x30,
    PD_1  = 0x31,
    PD_2  = 0x32,
    PD_3  = 0x33,
    PD_4  = 0x34,
    PD_5  = 0x35,
    PD_6  = 0x36,
    PD_7  = 0x37,
    PD_8  = 0x38,
    PD_9  = 0x39,
    PD_10 = 0x3A,
    PD_11 = 0x3B,
    PD_12 = 0x3C,
    PD_13 = 0x3D,
    PD_14 = 0x3E,
    PD_15 = 0x3F,

    PE_0  = 0x40,
    PE_1  = 0x41,
    PE_2  = 0x42,
    PE_3  = 0x43,
    PE_4  = 0x44,
    PE_5  = 0x45,
    PE_6  = 0x46,
    PE_7  = 0x47,
    PE_8  = 0x48,
    PE_9  = 0x49,
    PE_10 = 0x4A,
    PE_11 = 0x4B,
    PE_12 = 0x4C,
    PE_13 = 0x4D,
    PE_14 = 0x4E,
    PE_15 = 0x4F,

    PF_0  = 0x50,
    PF_1  = 0x51,
    PF_2  = 0x52,
    PF_3  = 0x53,
    PF_4  = 0x54,
    PF_5  = 0x55,
    PF_6  = 0x56,
    PF_7  = 0x57,
    PF_8  = 0x58,
    PF_9  = 0x59,
    PF_10 = 0x5A,
    PF_11 = 0x5B,
    PF_12 = 0x5C,
    PF_13 = 0x5D,
    PF_14 = 0x5E,
    PF_15 = 0x5F,

    PG_0  = 0x60,
    PG_1  = 0x61,
    PG_2  = 0x62,
    PG_3  = 0x63,
    PG_4  = 0x64,
    PG_5  = 0x65,
    PG_6  = 0x66,
    PG_7  = 0x67,
    PG_8  = 0x68,
    PG_9  = 0x69,
    PG_10 = 0x6A,
    PG_11 = 0x6B,
    PG_12 = 0x6C,
    PG_13 = 0x6D,
    PG_14 = 0x6E,
    PG_15 = 0x6F,
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

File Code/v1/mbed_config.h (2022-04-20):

/*
 * mbed SDK
 * Copyright (c) 2017 ARM Limited
 *
 * Licensed under the Apache License, Version 2.0 (the "License");
 * you may not use this file except in compliance with the License.
 * You may obtain a copy of the License at
 *
 * http://www.apache.org/licenses/LICENSE-2.0
 *
 * Unless required by applicable law or agreed to in writing, software
 * distributed under the License is distributed on an "AS IS" BASIS,
 * WITHOUT WARRANTIES OR CONDITIONS OF ANY KIND, either express or implied.
 * See the License for the specific language governing permissions and
 * limitations under the License.
 */

// Automatically generated configuration file.
// DO NOT EDIT, content will be overwritten.

#ifndef __MBED_CONFIG_DATA__
#define __MBED_CONFIG_DATA__

// Configuration parameters
#define LPTICKER_DELAY_TICKS                                                  0                                                                                                  // set by target:MCU_STM32WL
#define MBED_CONF_ALT1250_PPP_BAUDRATE                                        115200                                                                                             // set by library:ALT1250_PPP
#define MBED_CONF_ALT1250_PPP_PROVIDE_DEFAULT                                 0                                                                                                  // set by library:ALT1250_PPP
#define MBED_CONF_APP_MAIN_STACK_SIZE                                         4096                                                                                               // set by application
#define MBED_CONF_ATMEL_RF_ASSUME_SPACED_SPI                                  1                                                                                                  // set by library:atmel-rf[STM]
#define MBED_CONF_ATMEL_RF_FULL_SPI_SPEED                                     7500000                                                                                            // set by library:atmel-rf
#define MBED_CONF_ATMEL_RF_FULL_SPI_SPEED_BYTE_SPACING                        250                                                                                                // set by library:atmel-rf
#define MBED_CONF_ATMEL_RF_IRQ_THREAD_STACK_SIZE                              1024                                                                                               // set by library:atmel-rf
#define MBED_CONF_ATMEL_RF_LOW_SPI_SPEED                                      3750000                                                                                            // set by library:atmel-rf
#define MBED_CONF_ATMEL_RF_PROVIDE_DEFAULT                                    0                                                                                                  // set by library:atmel-rf
#define MBED_CONF_ATMEL_RF_USE_SPI_SPACING_API                                0                                                                                                  // set by library:atmel-rf
#define MBED_CONF_CELLULAR_AT_HANDLER_BUFFER_SIZE                             32                                                                                                 // set by library:cellular
#define MBED_CONF_CELLULAR_CONTROL_PLANE_OPT                                  0                                                                                                  // set by library:cellular
#define MBED_CONF_CELLULAR_DEBUG_AT                                           0                                                                                                  // set by library:cellular
#define MBED_CONF_CELLULAR_MAX_CP_DATA_RECV_LEN                               1358                                                                                               // set by library:cellular
#define MBED_CONF_CELLULAR_PRESENT                                            1                                                                                                  // set by library:cellular
#define MBED_CONF_CELLULAR_RANDOM_MAX_START_DELAY                             0                                                                                                  // set by library:cellular
#define MBED_CONF_CELLULAR_USE_APN_LOOKUP                                     0                                                                                                  // set by library:cellular
#define MBED_CONF_CELLULAR_USE_SMS                                            0                                                                                                  // set by library:cellular
#define MBED_CONF_DRIVERS_OSPI_CSN                                            OSPI_FLASH1_CSN                                                                                    // set by library:drivers
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

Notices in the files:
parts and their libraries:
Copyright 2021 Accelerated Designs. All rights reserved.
